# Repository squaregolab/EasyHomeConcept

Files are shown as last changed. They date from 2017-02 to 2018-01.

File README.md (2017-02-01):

# Easy Home Concept

## AVERTISEMENT
Ce projet étant encore en développement, il ne peut en aucun cas être utilisé en l'état dans une maison !

Nous n'avons pas encore abordé les différents problèmes liés à la securité ou encore l'interfaçage avec (par exemple)
des volets de constructeurs différents.

## Principe du projet

Le but de ce projet est de proposer un système simple et à bas coût afin de pouvoir domotiser sa maison.

Le but final du projet étant de pouvoir contrôler les principaux acteurs de la maison (lumière, volets, chauffage) ainsi que de pouvoir ajouter facilement au système divers acteurs.

## Solution utilisée

### Materiél

Pour le centre de contrôle, nous avons choisi une Raspberry Pi 3 ainsi qu'un écran tactile de 7".
Le choix s'est posé sur la Raspberry pi 3 car elle dispose du Wifi à l'origine ainsi que la facilité de connexion d'un écran.

Pour ce qui est des modules de contrôle, nous avons fait le choix d'en disposer un dans chaque pièce (aspect modulaire). Ces modules sont équipés d'un Adafruit Huzzah ainsi qu'un GPIO Expander (MCP23008).

### Logiciel

Le programme de la Rapsberry est en fait le serveur, les modules sont donc les clients.

Le serveur ainsi que l'interface de la raspberry sont développé en Java (JavaFx pour l'interface) avec l'IDE Intellig IDEA.
Les différentes bibliothèques utilisées sont présente dans Libraries, les sources sont également disponibles.

Pour les Huzzahs, le programe est développé en C++/Arduino via PlatforIO (extention de Atom).
Les sources sont également disponibles dans Sources.

### Communication

La Communication Serveur/Clients se fait pour le moment via une connection TCP/IP.

#### Presentation des trames

###### Trame de demande:
>`<q>`
><p>Le serveur envoi une demande d'actualisation au client.</p>

###### Trame de commande:
>`<c,"ID","valeur">`
><p>Le serveur envoi une commande identifiée par un ID numérique suivi par la valeur à appliquer, le tout séparé par une virgule. </p>
> <p>A l'heure actuelle, les commandes disponibles sont les suivantes</p>
>
> 1. Lumière<br> ID => 1<br>Commandes:
>     * 0 = Eteindre
>     * 1 = Allumer
> 1. Volets<br> ID => 2<br>Commandes:
>     * 0 = Stop
>     * 1 = Fermer
>     * 2 = Ouvrir
> 1. Température Cible<br>ID => 3<br>Commande: _Température_
> 1. Chauffage<br>ID => 4<br>Commandes:
>     * 0 = Eteindre
>     * 1 = Allumer  

###### Trame de réponse:
>>La trame de réponse suivante est donnée pour les modules que nous avons conçu. Cette trame pourra être modifiée afin d'accepter des modules divers.

>`<r,"IDmodule","Temperature","TemperatureCible","Humidité","EtatLumiere","EtatVollet","ConsoEau","EtatChauffage">`
>

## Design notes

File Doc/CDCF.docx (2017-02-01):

Promotion 2016-2019 | Imerir

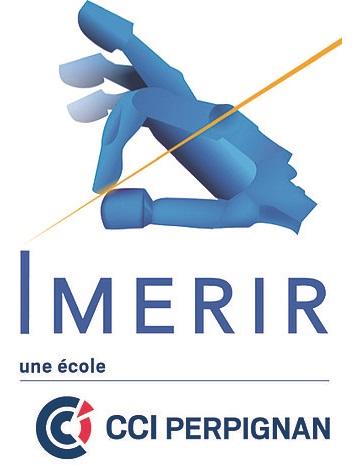
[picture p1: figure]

CDCF

Maison domotique

REY Clément

CLEMENT Sébastien

08 décembre 2016

Version 1.0

# Sommaire

Expression fonctionnel du besoin 2

Réaliser une installation domotique 2

# Expression fonctionnel du besoin

## Réaliser une installation domotique

L’application doit permettre :

- de connaître :
  - la température et l’humidité dans la maison.
  - des données tel que la consommation d’eau et d'électricité
- de contrôler :
- l’éclairage
- les volets
- la climatisation / chauffage

Le système doit être pilotable depuis un écran de contrôle tactil.

Les données doivent être consultable sur une application mobile qui peut aussi permettre de contrôler les éléments de la maison.

L'installation doit être facile.

Il doit y avoir une possibilité d’ajouter des éléments (capteur, actionneur)

CDCF_REY-CLEMENT_V1.0

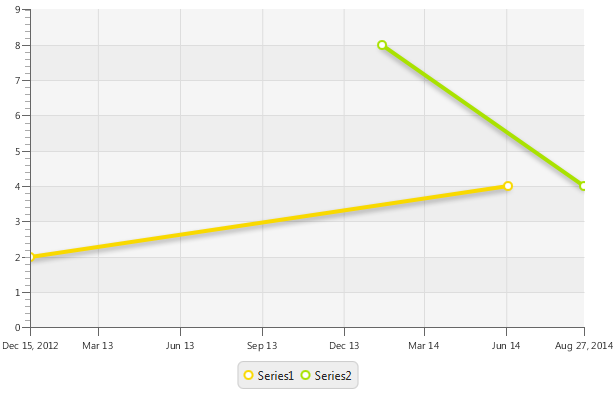
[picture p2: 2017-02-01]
Sources/InterfacePi/src/extfx/scene/chart/doc-files/DateAxisMonths.png

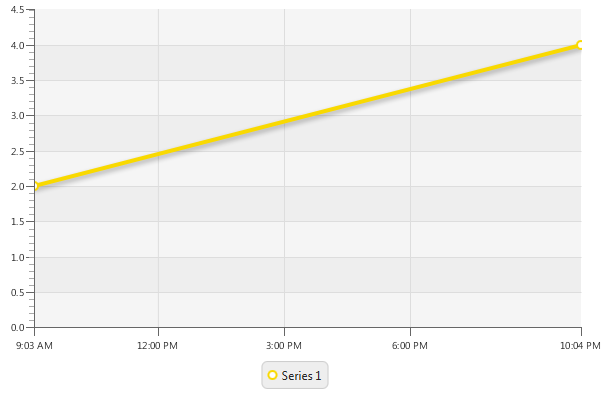
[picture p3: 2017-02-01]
Sources/InterfacePi/src/extfx/scene/chart/doc-files/DateAxisHours.png

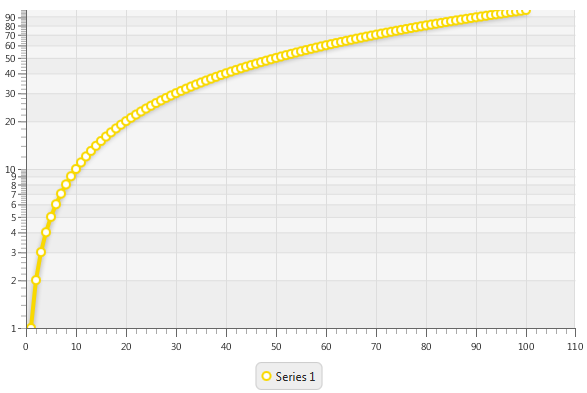
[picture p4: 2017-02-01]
Sources/InterfacePi/src/extfx/scene/chart/doc-files/LogarithmicAxis.png

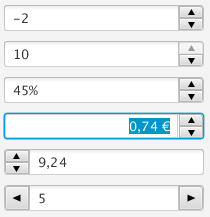
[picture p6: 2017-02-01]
Sources/InterfacePi/src/extfx/scene/control/doc-files/NumberSpinner.png

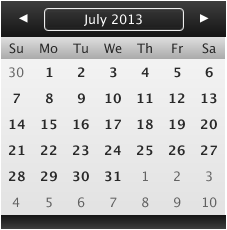
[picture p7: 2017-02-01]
Sources/InterfacePi/src/extfx/scene/control/doc-files/CalendarView.png

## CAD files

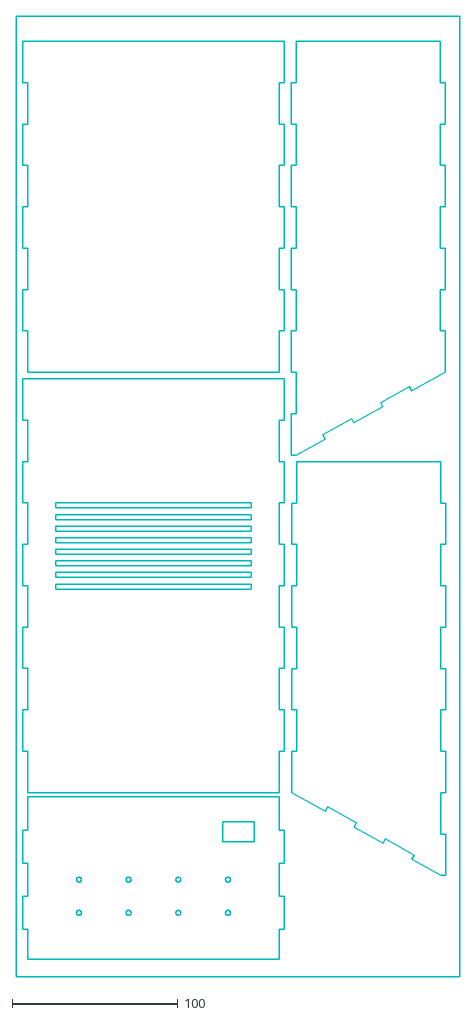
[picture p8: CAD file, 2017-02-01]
Sources/Modeles sketchups/Boitier Alim stabilisée/dessin.dxf
268.0 x 580.0

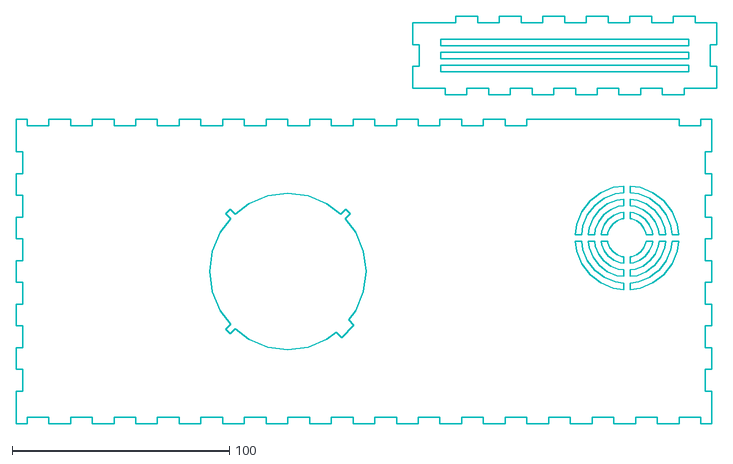
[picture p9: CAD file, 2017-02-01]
Sources/Modeles sketchups/Boitier RaspB - ecran tactil/boitier1.dxf
322.4 x 187.4

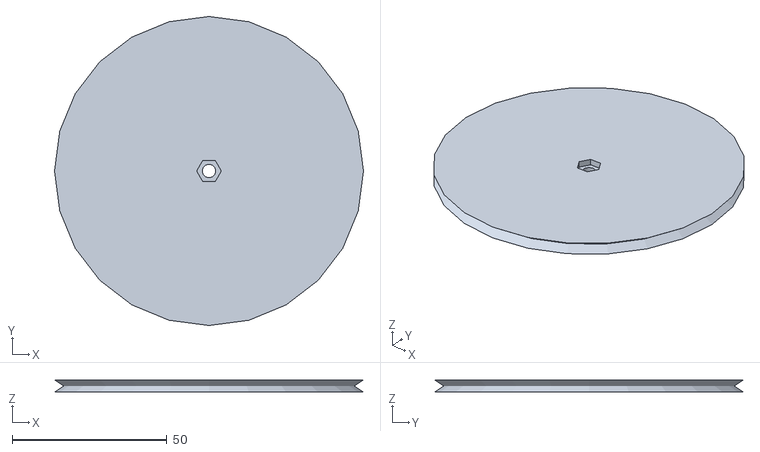
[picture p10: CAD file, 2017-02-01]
Sources/Modeles sketchups/coupleur moteur/démultiplicateur.stl
100.0 x 100.0 x 4.00

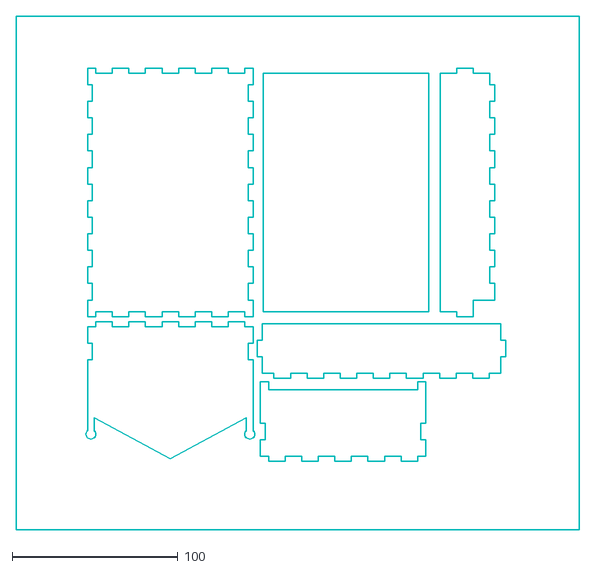
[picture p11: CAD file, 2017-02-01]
Sources/Modeles sketchups/Lit huzzah/dessin.dxf
340.0 x 310.0

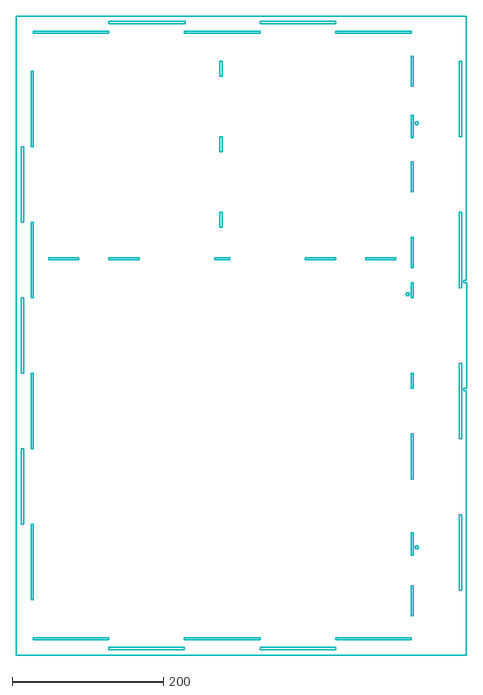
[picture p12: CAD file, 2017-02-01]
Sources/Modeles sketchups/Maquette maison/plaque1.dxf
597.0 x 846.0

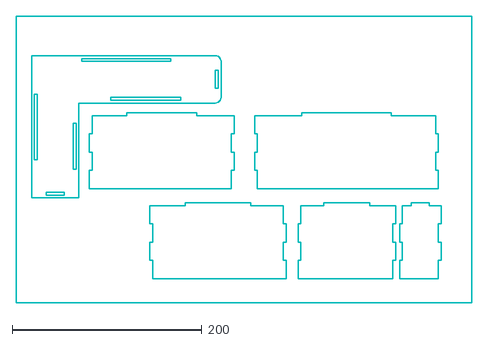
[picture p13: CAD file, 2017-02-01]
Sources/Modeles sketchups/Meuble/meubles1.dxf
481.0 x 302.0

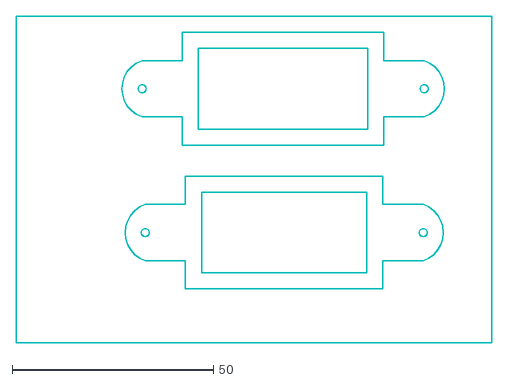
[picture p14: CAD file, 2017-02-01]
Sources/Modeles sketchups/support moteur/dessin.dxf
118.0 x 81.0

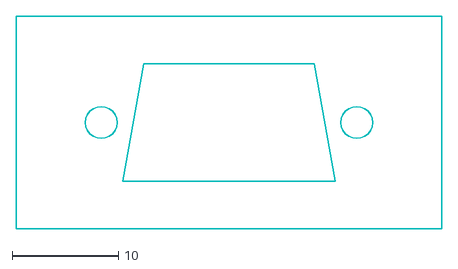
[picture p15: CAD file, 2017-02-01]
Sources/Modeles sketchups/Tableau elec/dessin.dxf
40.0 x 20.0

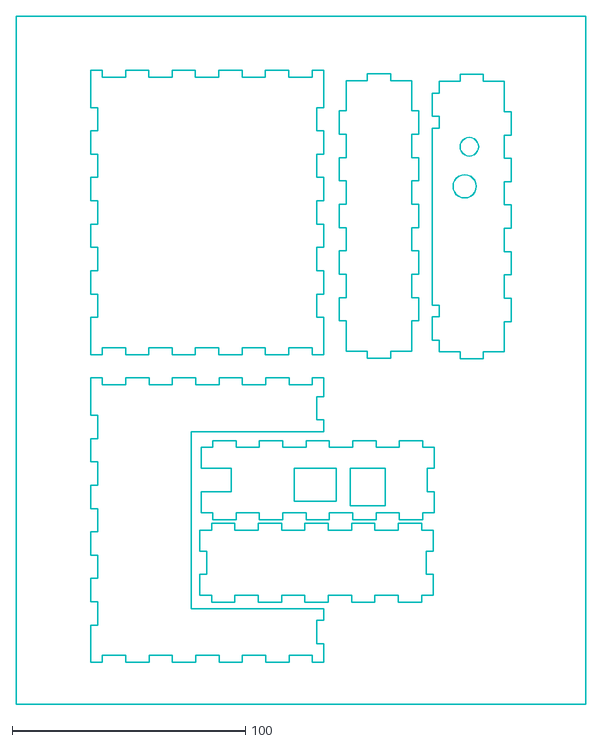
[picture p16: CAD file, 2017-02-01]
Sources/Modeles sketchups/Tele/dessin-1.dxf
244.0 x 295.0

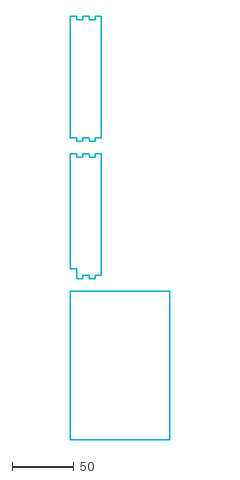
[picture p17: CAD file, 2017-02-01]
Sources/Modeles sketchups/ventilo/dessin.dxf
80.0 x 342.0

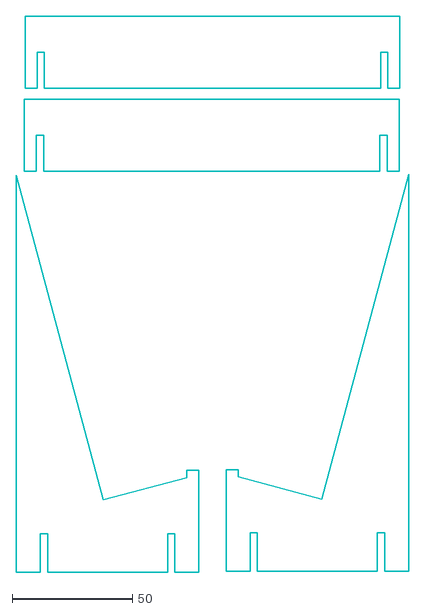
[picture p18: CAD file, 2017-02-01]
Sources/Modeles sketchups/Boitier RaspB - ecran tactil/porte boitier.dxf
163.3 x 231.5

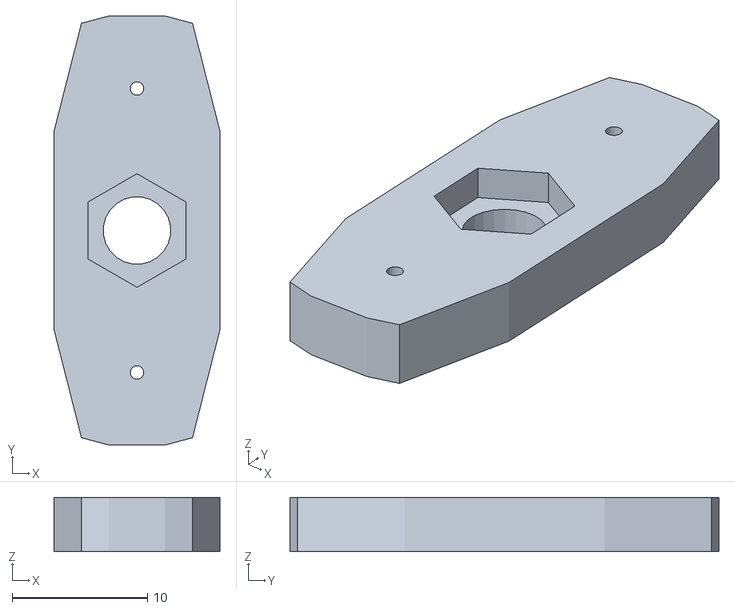
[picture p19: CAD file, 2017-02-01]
Sources/Modeles sketchups/coupleur moteur/coupleur moteur2.stl
12.2 x 31.7 x 4.00

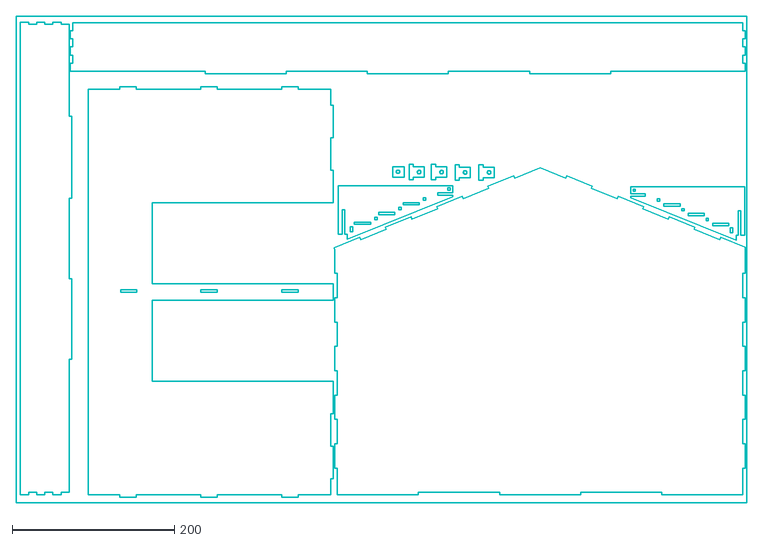
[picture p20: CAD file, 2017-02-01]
Sources/Modeles sketchups/Maquette maison/plaque4.dxf
900.0 x 600.0

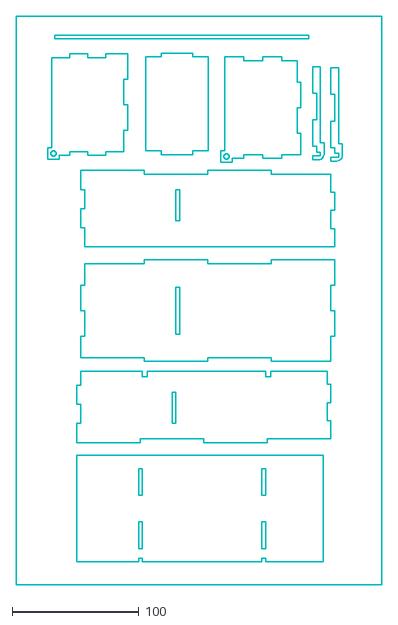
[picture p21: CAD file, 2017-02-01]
Sources/Modeles sketchups/Meuble/dessin4.dxf
288.0 x 448.0

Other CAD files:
Sources/Modeles sketchups/ventilo/dessin-1.dxf
Sources/Modeles sketchups/coupleur moteur/coupleur moteur0.stl
Sources/Modeles sketchups/Maquette maison/plaque5.dxf
Sources/Modeles sketchups/Meuble/tapis.dxf
Sources/Modeles sketchups/Boitier Alim stabilisée/Alim stabilisée.skp
Sources/Modeles sketchups/Boitier RaspB - ecran tactil/Boitier RaspB - ecran tactil.skp
Sources/Modeles sketchups/Lit huzzah/Lit huzzah.skp
Sources/Modeles sketchups/Maquette maison/Maquette maison.skp
Sources/Modeles sketchups/Maquette maison/plaque2.dxf
Sources/Modeles sketchups/Maquette maison/plaque3.dxf
Sources/Modeles sketchups/Meuble/dessin2.dxf
Sources/Modeles sketchups/Meuble/dessin3.dxf
Sources/Modeles sketchups/Meuble/meuble2.skp
Sources/Modeles sketchups/Meuble/meubles.skp
Sources/Modeles sketchups/Meuble/meubles4.skp
Sources/Modeles sketchups/Meuble/tapis2.dxf
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

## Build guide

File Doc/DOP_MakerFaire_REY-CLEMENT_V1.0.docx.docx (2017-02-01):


Promotion 2016-2019

Imérir

Dossier d’Organisation Projet

Domotique sur Raspberry PI

Clément Rey

Sébastien Clément

06/12/16

Version 1.0

Ref DOP_Domotique_REY-CLEMENT_V1.0

# Historique des versions

Version | date | Modifications | Pages modifiées (1)
0.1 | 06/12/16 | Création du document | toutes

(1) si modification globale, indiquer « toutes »

# Sommaire

1. Cadre et objectifs du projet

2. Tâches et planning

3. Organisation

4. Tableau des risques

5. Qualité

6. Capitalisation de l’expérience

# 1. Cadre et objectifs du projet

Dans le cadre du salon « Mini Maker Faire » organisé par l’IMERIR fin janvier, nous avons choisi de réaliser un projet de domotique. L’objectif de ce projet est de réaliser une maquette d’application fonctionnelle à présenter le jour du salon.

# 2. Tâches

- Mise en place du projet
  - Rédiger les documents de gestion et planning
  - Créer dépôt pour le travail collaboratif
  - Définir la charte graphique
  - Définir le matériel nécessaire
  - Faire passer la commande de matériel
- Programmation
  - Programmation de la Raspberry
    - Configuration / installation de la raspberry
    - Gérer la centralisation des données
    - Gérer la commande des élément distants
    - Créer l'interface graphique pour l'écran
    - Gérer l'envoi de données vers la database
  - Programmation des éléments distants
    - Gérer l'envoie des données vers raspberry
    - Gérer la réception des commandes de la raspberry
- Modélisation
  - Dessin des plans de la maquette
  - Impression de la maquette
  - Montage des modules

Montage maquette

# 3. Organisation

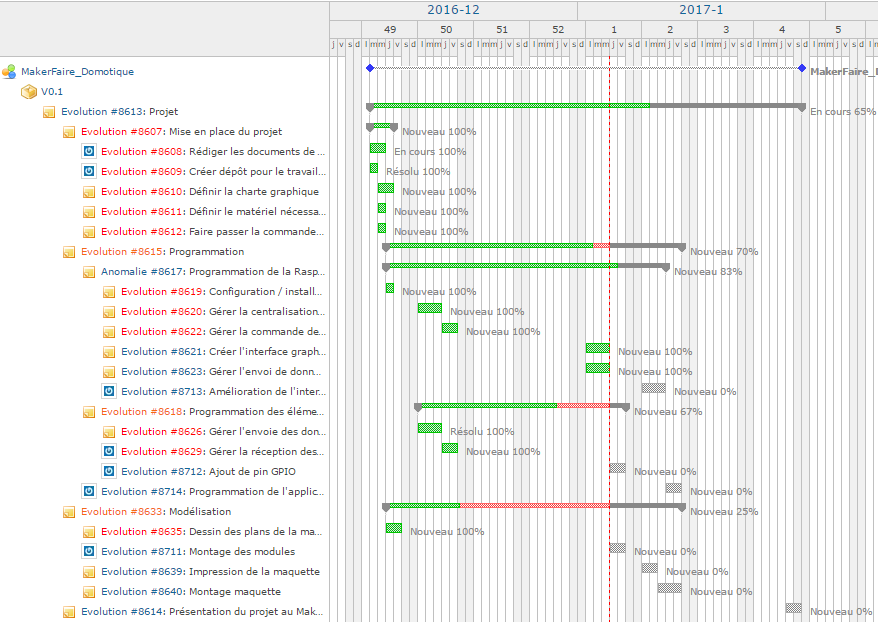
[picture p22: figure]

# 4. Tableau des risques

Management | Proba | Gravité | Criticité | Actions | responsable | etat
Retard projet | 2 | 5 | 10 | Bien planifier les différentes tâches du projet | chef de projet | ok
Manque d'information | 3 | 4 | 12 | Organiser des réunions de points au moins une fois par semaine | chef de projet | ok
Equipe Malade | 1 | 3 | 3 | Dispersion des tâches en urgence si cela arrive | chef de projet | ok
Manque d’information sur le projet | 2 | 5 | 10 | Organiser des réunions de points au moins une fois par semaine | chef de projet | ok
Test non suffisant | 2 | 3 | 6 | Mettre en place une grille de tests | développeur | ok
Mauvaise estimation complexité | 3 | 3 | 9 | Pas d’action | 0 | 0
Travail trop lent | 1 | 4 | 4 | Faire un suivie d'avancement du projet | chef de projet | ok

Généraux
Accident | 1 | 3 | 3 | Pas d’action | 0 | 0

Technique
PB Réseaux | 1 | 4 | 4 | faire des essaie / prévoir solution de secour | développeur | ok
PB électrique | 1 | 4 | 4 | prévoir suffisamment de matériel | développeur | ok
BUG inexpliqué | 2 | 3 | 6 | documenter et commenter | développeur | ok
Sauvegarde insuffisante | 2 | 5 | 10 | Sauvegarde automatique | développeur | ok
Disque dur corrompu | 1 | 5 | 5 | Faire des sauvegardes sur d'autre support | chef de projet | ok
Bloquage technique | 4 | 4 | 16 | Anticiper les axes qui poseront problème / Contourné le problème | développeur | ok
Sauvegarde corrompu | 1 | 5 | 5 | Faire des sauvegardes sur d'autre support | chef de projet | ok
Programme mal organisé et illisible | 3 | 4 | 12 | Règles de codage ==> développeur qui vérifie régulièrement | développeur | ok

# 5. Qualité

La qualité du projet final pourra être classé en 4 points:

- Qualité faible:

Relevé de mesure en interne via un écran.

- Qualité moyenne

Relevé de mesure et commande d'appareil en interne via écran tactile.

- Qualité haute:

Relevé de mesure et commande d’appareil depuis une application

- Qualité optimal

Relevé de mesure et commande d’appareil depuis une application mobile, possibilité d’ajouter facilement de nouveau modules

# 6. Capitalisation de l’expérience

Cette expérience a permis de mettre en place les outils de gestion vus en cours. Nous avons travaillé presque totalement en indépendance et nous avons ainsi développé de multiples compétences techniques.

La segmentation et la répartition des tâches au départ étaient plutôt juste malgré un léger glissement dû à la quantité de travail qui n'a toutefois pas entraîné de retard.

Si un tel projet était à refaire il serait préférable de faire une meilleur estimation de la quantité de travail afin de faire appel à plus de mains d’oeuvre.

DOP_Domotique_REY-CLEMENT_V1.0

Dossier d’Organisation Projet

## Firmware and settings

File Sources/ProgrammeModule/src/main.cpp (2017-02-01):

#include <ESP8266WiFi.h>
#include <Arduino.h>
#include <ESP8266WiFiMulti.h>
#include <String.h>
#include <string>
#include <WiFiClient.h>
#include <DHT.h>
#include <Wire.h>
#include <Adafruit_MCP23008.h>
#include <Servo.h>


// Data wire is plugged into port 13 on the Arduino
// Connect a 4.7K resistor between VCC and the data pin (strong pullup)
#define DHTPIN 13
#define DHTTYPE DHT22
DHT dht(DHTPIN,DHTTYPE);

Servo myservo;  // create servo object to control a servo
Adafruit_MCP23008 mcp; // create an extender object for more GPIO
ESP8266WiFiMulti WiFiMulti; // Use WiFiClient class to create TCP connections
WiFiClient client; // Client define as wifi target

// WiFi credentials.
const char* WIFI_SSID = ""; // The wifi name
const char* WIFI_PASS = ""; // The password
// If it's an open network, no need of PW;   !! Remove WIFI_PASS of WiFiMulti.addAP() func !!

const char* CLIENT_IP = "XX.XX.XX.XX";
const uint16_t CLIENT_PORT = 75; // Don't forget to open a port on your client


/******************************************************************
************************ Globals variables ************************
******************************************************************/

int id = 1; // Use one ID per rooms, don't forget to change between each.

float temp = 20;
float humi = 40;
bool etat_lum = 0;
bool etat_chauffage = 0;
int etat_volet = 1;
int waterConso = 0;

int cmd_lum = 0;
int cmd_volet = 0;
float cmd_temp = 18;

String splitedS[10];  // la trame recu de la raspberry découpé dans un tableau (<"type de trame C","numero de l'objet","etat de l'objet")

/*****************************************************************/
/****************** Déclaration des setup ************************/
/*****************************************************************/

void networkSetup()
{
    Serial.begin(115200);
    while(!Serial) { }

    // We start by connecting to a WiFi network
    WiFiMulti.addAP(WIFI_SSID, WIFI_PASS);
    // If it's an open network, no need of PW
    // !! Remove WIFI_PASS of WiFiMulti.addAP() func !!

    Serial.println();
    Serial.println();
    Serial.print("Wait for WiFi... ");

    while(WiFiMulti.run() != WL_CONNECTED)
    {
        Serial.print(".");
        delay(500);
    }

    Serial.println("");
    Serial.println("WiFi connected");
    Serial.println("IP address: ");
    Serial.println(WiFi.localIP());

    delay(500);

    Serial.print("connecting to ");
    Serial.println(CLIENT_IP);

    if (!client.connect(CLIENT_IP, CLIENT_PORT))
    {
        Serial.println("connection failed");
        Serial.println("wait 5 sec...");
        delay(5000);
    }
    else
    {
        client.println("<a," +String(id)+ ">"); // Send to the client your ID to open or not the connetion
        // if ID already use or not set in interface's parameters, the connexion is closed by the raspberry
    }
}

void pinSetup()
{
    pinMode (0,OUTPUT);
    digitalWrite (0,HIGH);
    myservo.attach(14);
    dht.begin();
}

void extenderSetup()
{
    mcp.begin();      // use default address 0

    mcp.pinMode(0, OUTPUT); //Moteur volet              // Shutter's Servo data
    mcp.pinMode(1, OUTPUT); //Libre                     // free pin
    mcp.pinMode(2, OUTPUT); //Ventilation               // Switch 1:on/0:off for the blower
    mcp.pinMode(3, OUTPUT); //Chaud                     // set the blower as heater
    mcp.pinMode(4, OUTPUT); //Froid                     // set the blower as cooler
    mcp.pinMode(5, INPUT);  //Consomation d'eau         // Water outflow counter
    mcp.pinMode(6, INPUT);  //Libre                     // free pin
    mcp.pinMode(7, OUTPUT); //Lumière                   // Light control

}

/*****************************************************************/
/*****************************************************************/
/*****************************************************************/

void getData()
{
    // Reading temperature or humidity takes about 250 milliseconds!
    // Sensor readings may also be up to 2 seconds 'old' (its a very slow sensor)
    float h = dht.readHumidity();
    humi = h;

    // Read temperature as Celsius (the default)
    float t = dht.readTemperature();
    temp = t;

    // Check if any reads failed and exit early (to try again).
    if (isnan(h) || isnan(t))
    {
        Serial.println("Failed to read from DHT sensor!");
        return;
    }

    // Serial.print("Humidity: ");
    // Serial.print(h);
    // Serial.print(" %\t");
    // Serial.print("Temperature: ");
    // Serial.print(t);
    // Serial.println(" *C ");
}

/*****************************************************************/
/*****************************************************************/

// Use to split the request string into usable datas
int splitString(String request, char separator)
{
    String curentString="                   ";
    memset(splitedS,0,sizeof(splitedS));
    int numChamp = 0, numLettre = 0;

    for (int i = 1 ; i < request.length() ; i++)
    {
        // each time there is a separator the currentString is push in the splitedS tab
        if (request[i] == separator || request[i] == '>')
        {
            curentString.remove(numLettre);
            splitedS[numChamp] = curentString;
            curentString="                   ";

            numLettre=0;
            numChamp++;
        }
        // all consecutive char is puch at the end of the currentString
        else
        {
            curentString.setCharAt(numLettre,request.charAt(i));
            numLettre++;
        }
    }
    return numChamp; // return the number of string in the splitedS tab
}

/*****************************************************************/
/*****************************************************************/

void lightControl()
{
    if (cmd_lum)
    {
        //Serial.println("Lumière alumée");
        mcp.digitalWrite (7,HIGH);
    }
    else
    {
        //Serial.println("Lumière éteinte");
        mcp.digitalWrite (7,LOW);
    }
}

/*****************************************************************/
/*****************************************************************/

void temperatureControl()
{
    //the blower system will turn off when the temperature is close to the target. Here 0.5 °c

    //Serial.print("Ventillation en mode : ");
    if (cmd_temp > (temp+0.5) && etat_chauffage)
    {
        //Serial.println("Chauffage");
        mcp.digitalWrite (2,HIGH);
        mcp.digitalWrite (3,HIGH);
        mcp.digitalWrite (4,LOW);
    }
    else if (cmd_temp < (temp-0.5) && etat_chauffage)
    {
        //Serial.println("Climatisation");
        mcp.digitalWrite (2,HIGH);
        mcp.digitalWrite (3,LOW);
        mcp.digitalWrite (4,HIGH);
    }
    else
    {
        //Serial.println("Arret");
        mcp.digitalWrite (2,LOW);
        mcp.digitalWrite (3,LOW);
        mcp.digitalWrite (4,LOW);
    }

}

/*****************************************************************/
/*****************************************************************/

// This fonction need to be revised to add other datas in the transmisons if necessary
void sendData()
{
    static long timer = 0;
    // to avoid more than 1 getData() each 2 seconds; due to the slowness of DHT22
    if (timer <= millis())
    {
        getData();
        timer = millis() + 2000;
    }
    // datas need to be turned into string before sending
    String toSend = "<r," + String(id) + "," +String(temp)+ "," +String(cmd_temp)+ "," +String(humi)+ "," +String(etat_lum)+ "," +String(etat_volet)+ "," +String(waterConso)+","+ String(etat_chauffage)+">";
    client.println(toSend); // This will send the request to the raspberry
    waterConso = 0;
}

/*****************************************************************/
/*****************************************************************/

void shutterControl()
{
    #define tempsFonc 20
    //this are the differents commands
    #define stop 0
    #define fermer 1
    #define ouvrir 2
    //this are the differents states
    #define entreOuvert 0
    #define ferme 1
    #define ouvert 2
    #define montee 3
    #define descente 4

    #define min 0
    #define max 180
    #define speed 1

    static long shutterTimer = millis();
    long actualTime = millis();
    static int pos = min;

    switch (cmd_volet)
    {
        case stop:
          if (min < pos && pos < max)
            etat_volet = entreOuvert;
          if (pos > max)
            etat_volet = ouvert;
          if (pos < min)
            etat_volet = ferme;
          break;
        case ouvrir :
          if (pos < max)
          {
              if (shutterTimer < actualTime)
              {
                  pos += speed;
                  shutterTimer = actualTime + tempsFonc;
              }
              etat_volet = montee;
          }
          else
          {
              etat_volet = ouvert;
          }
          break;
        case fermer :
          if (min < pos)
          {
              if (shutterTimer < actualTime)
              {
                  pos -= speed;
                  shutterTimer = actualTime + tempsFonc;
              }
              etat_volet = descente;
          }
          else
          {
              etat_volet = ferme;
          }
          break;
        default :
          Serial.println("Erreur case volet");
    }
    if (id == 1)
        myservo.write(pos);
    if (id == 2)
      myservo.write(180-pos); // ferme le volet dans l'autre sens
      // close the shutter in the other way around
}

/*****************************************************************/
/*****************************************************************/

void whatToDo(String cmdIDS, String cmdDataS)
{
    // this are the possibles values of the second field of the frame
    // they are IDs of the devices to control
    #define light 1
    #define volet 2
    #define temperature 3
    #define OnOff_temp 4

    // when the system recive a frame like : <c,IDofCommand,ValueOfCommand> this function occures
    // the IDofCommand is use for the switch, then the new value is push into the variables and call the assotiate contol function
    int cmdID = cmdIDS.toInt();
    switch (cmdID)
    {
        case light : //identifiant pour la lumiere
          cmd_lum = cmdDataS.toInt();
          etat_lum = cmd_lum;
          lightControl();
          break;
        case volet : //identifiant pour les volet
          cmd_volet = cmdDataS.toInt();
          shutterControl();
          break;
        case temperature : //identifiant pour le controle de la température
          cmd_temp = cmdDataS.toFloat();
          temperatureControl();
          break;
        case OnOff_temp :
          etat_chauffage = cmdDataS.toInt();
          break;
    }
    sendData();
}

/*****************************************************************/
/*****************************************************************/

void frameTraitment()
{
    // This function read the buffer char by char from '<' until '>'
    #define closed 0
    #define open 1
    static String request;
    static bool first = true;
    String finalRequest;

    static bool trame = closed;
    char newChar;


    if(first)
    {
        request.reserve(24);
        first = false;
    }
    newChar = client.read();

    if (newChar == '<')
    {
        trame = open;
        request = '<';
    }
    else if (trame == open)
    {
        if ('!' < newChar && newChar < '~')
        {
            request=request+newChar;
            if (newChar == '>')
            {
                trame = closed;
                finalRequest = request;
                request = "";
            }
        }
        else
        {
           request = "";
        }
        if (trame == closed)
        {
            int nbSeparator = splitString(finalRequest, ',');
            for (int i = 0; i < nbSeparator; i++)
            {
                if (splitedS[i] == "c")
                {
                    whatToDo(splitedS[i+1],splitedS[i+2]);
                    finalRequest = "";
                    break;
                }
                else if (splitedS[i] == "q")
                {
                    sendData();
                    finalRequest = "";
                }
            }
        }
    }
}

/*****************************************************************/
/*****************************************************************/

bool wifiTest()
{
    if(WiFi.status() != WL_CONNECTED) // test de connection au reseau wifi
    {
        Serial.println("Disconnected from WiFi");
    }
    return WiFi.status();
}

/*****************************************************************/
/*****************************************************************/

bool testClient()
{
    if (!client.connected())
    {
        Serial.println("Disconnected from Client");
        while (!client.connect(CLIENT_IP, CLIENT_PORT))
        {
            Serial.println("wait 5 sec...");
            delay(5000);
            Serial.println("Reconnection failed");
        }
        client.println("<a," +String(id)+ ">");
        Serial.println("Reconnected to Client");
    }
    return client.connected();
}

/*****************************************************************/
/*****************************************************************/

void waterCounter()
{
    // for a sensor that return pulse for one liter
    if (mcp.digitalRead(5) == true )
    {
        waterConso = 1;
    }
}

/******************************************************************
**************************** Setup ********************************
******************************************************************/

void setup()
{
    networkSetup();
    pinSetup();
    extenderSetup();
}

/******************************************************************
**************************** Loop *********************************
******************************************************************/

void loop()
{
    if(testClient() && wifiTest()) // test de connection au client
    {
        frameTraitment();
        lightControl();
        shutterControl();
        temperatureControl();
        waterCounter();
    }

}

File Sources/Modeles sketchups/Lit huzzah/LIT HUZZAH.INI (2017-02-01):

[Technics_Laser_Data]
ModifyTechCFG=2
LayersNumber=1
ExportRows=1
ExportColumns=1
ExportRowSpace=0.00000
ExportColumnSpace=0.00000
ExportRowCW=0.00000
ExportColumnCW=0.00000
LogicOrgPositionX=734.10232
LogicOrgPositionY=423.84083
LogicOrgPositionZ=-9999999.00000
AtOnceExport=1
IsTwoLaserWorking=1
TableZeroPositionX=0.00000
TableZeroPositionY=0.00000
OutputTimes=1
DelayTime=0
FeedLength=0.00000
FeedSpeed=5.00000
FeedDelayTime=0
MinX=322.03483
MaxX=734.10232
MinY=189.25960
MaxY=423.84083
ChangeSerialNo=0
ArrayMinX=322.03483
ArrayMaxX=734.10232
ArrayMinY=189.25960
ArrayMaxY=423.84083
ClipBoxPower=40.00000
ClipBoxPower2=40.00000
ClipBoxOffsetLen=2.00000
ClipBoxSpeed=25.00000
AlignMachineZPos=0.00000
RouteLength=0.00000
RoutePointNumber=0
OffsetLaserPower=0.00000
OffsetWorkSpeedPer=1.00000
ZHeightForLaserFocus=0.00000
LayerColor_0=32768
[CoordSystem_0]
LogicOrgPosition1=734.10232
LogicOrgPosition2=423.84083
LogicOrgPosition3=-9999999.00000
SPLITBLOCK_NUMBER=0
[CreateTechnicsCodeMgr]
PrjHasModifyCFG=1
[TechnicsLayers_16776960]
TechnicsMode=TECHNICS_LASERCUT
LaserCutConnerPower=20.00000
LaserCutWorkPower=100.00000
LaserCutConnerPower2=30.00000
LaserCutWorkPower2=50.00000
LaserCutFrequency=20000
LaserCutOptimizePathType=1
LaserCutInnerToOuter=1
LaserCutInnerToOuter2=0
LaserCutDownToUpper=1
LaserCutBlockHeight=150.00000
LaserCutAutoSetPathDir=1
LaserCutCicleMinSegNumber=36
LaserCutDisperseLength=0.02000
LaserCutCloseGapLength=0.11000
LaserCutOverlapLength=0.00000
LaserCutAdjustForClose=0
LaserCutQXEnterLength=0.00000
LaserCutDelayMoveTime=0.00000
LaserCutOpenGZDelayTime=0.00000
LaserCutOpenLaserDelayTime=0.00000
LaserCutCloseLaserDelayTime=0.00000
LaserCutDelayTimeAfterCloseLaser=0.00000
LaserCutOneAxisBackLashLength=0.00000
LaserCutTwoAxisBackLashLength=0.00000
LaserCutBackLashAddSpaceLength=8.00000
LaserCutBlowGasType=2
LaserCutAheadBlowGasTimes=0.00000
LaserCutNoCloseGasTimes=0.00000
LaserCutSpeed=15.00000
LaserCutGWAcc=120.00000
LaserCutGWTime=0.01000
LaserCutTrackSize=100
LaserCutLineLength=0.00000
SpaceCutLineLength=0.00000
bSpaceLineFirst=0
LaserCutAdjustMove=0
LaserCutAdjustMoveDelay=0.00000
LaserCutUpLen=0.00000
LaserCutCircleSpeedNum=0
[TechnicsLayers_8421376]
TechnicsMode=TECHNICS_LASERCUT
LaserCutConnerPower=20.00000
LaserCutWorkPower=100.00000
LaserCutConnerPower2=30.00000
LaserCutWorkPower2=50.00000
LaserCutFrequency=20000
LaserCutOptimizePathType=1
LaserCutInnerToOuter=1
LaserCutInnerToOuter2=0
LaserCutDownToUpper=1
LaserCutBlockHeight=150.00000
LaserCutAutoSetPathDir=1
LaserCutCicleMinSegNumber=36
LaserCutDisperseLength=0.02000
LaserCutCloseGapLength=0.11000
LaserCutOverlapLength=0.00000
LaserCutAdjustForClose=0
LaserCutQXEnterLength=0.00000
LaserCutDelayMoveTime=0.00000
LaserCutOpenGZDelayTime=0.00000
LaserCutOpenLaserDelayTime=0.00000
LaserCutCloseLaserDelayTime=0.00000
LaserCutDelayTimeAfterCloseLaser=0.00000
LaserCutOneAxisBackLashLength=0.00000
LaserCutTwoAxisBackLashLength=0.00000
LaserCutBackLashAddSpaceLength=8.00000
LaserCutBlowGasType=2
LaserCutAheadBlowGasTimes=0.00000
LaserCutNoCloseGasTimes=0.00000
LaserCutSpeed=15.00000
LaserCutGWAcc=120.00000
LaserCutGWTime=0.01000
LaserCutTrackSize=100
LaserCutLineLength=0.00000
SpaceCutLineLength=0.00000
bSpaceLineFirst=0
LaserCutAdjustMove=0
LaserCutAdjustMoveDelay=0.00000
LaserCutUpLen=0.00000
LaserCutCircleSpeedNum=0
[TechnicsLayers_8388672]
TechnicsMode=TECHNICS_LASERCUT
LaserCutConnerPower=20.00000
LaserCutWorkPower=100.00000
LaserCutConnerPower2=30.00000
LaserCutWorkPower2=50.00000
LaserCutFrequency=20000
LaserCutOptimizePathType=1
LaserCutInnerToOuter=1
LaserCutInnerToOuter2=0
LaserCutDownToUpper=1
LaserCutBlockHeight=150.00000
LaserCutAutoSetPathDir=1
LaserCutCicleMinSegNumber=36
LaserCutDisperseLength=0.02000
LaserCutCloseGapLength=0.11000
LaserCutOverlapLength=0.00000
LaserCutAdjustForClose=0
LaserCutQXEnterLength=0.00000
LaserCutDelayMoveTime=0.00000
LaserCutOpenGZDelayTime=0.00000
LaserCutOpenLaserDelayTime=0.00000
LaserCutCloseLaserDelayTime=0.00000
LaserCutDelayTimeAfterCloseLaser=0.00000
LaserCutOneAxisBackLashLength=0.00000
LaserCutTwoAxisBackLashLength=0.00000
LaserCutBackLashAddSpaceLength=8.00000
LaserCutBlowGasType=2
LaserCutAheadBlowGasTimes=0.00000
LaserCutNoCloseGasTimes=0.00000
LaserCutSpeed=15.00000
LaserCutGWAcc=120.00000
LaserCutGWTime=0.01000
LaserCutTrackSize=100
LaserCutLineLength=0.00000
SpaceCutLineLength=0.00000
bSpaceLineFirst=0
LaserCutAdjustMove=0
LaserCutAdjustMoveDelay=0.00000
LaserCutUpLen=0.00000
LaserCutCircleSpeedNum=0
TechnicsNeedOutput=0
[TechnicsLayers_1048455]
TechnicsMode=TECHNICS_LASERCUT
LaserCutConnerPower=20.00000
LaserCutWorkPower=100.00000
LaserCutConnerPower2=30.00000
LaserCutWorkPower2=50.00000
LaserCutFrequency=20000
LaserCutOptimizePathType=1
LaserCutInnerToOuter=1
LaserCutInnerToOuter2=0
LaserCutDownToUpper=1
LaserCutBlockHeight=150.00000
LaserCutAutoSetPathDir=1
LaserCutCicleMinSegNumber=36
LaserCutDisperseLength=0.02000
LaserCutCloseGapLength=0.11000
LaserCutOverlapLength=0.00000
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

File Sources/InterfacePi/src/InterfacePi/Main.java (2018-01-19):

package InterfacePi;


import InterfacePi.Communication.ClientS;
import InterfacePi.Communication.CommunicationScript;
import InterfacePi.Communication.ModuleLauncher;
import com.pi4j.io.gpio.*;
import com.pi4j.system.SystemInfo;
import javafx.application.Application;
import javafx.event.EventHandler;
import javafx.fxml.FXMLLoader;
import javafx.scene.Parent;
import javafx.scene.Scene;
import javafx.scene.input.MouseEvent;
import javafx.scene.paint.Color;
import javafx.stage.Stage;
import org.apache.logging.log4j.LogManager;
import org.apache.logging.log4j.Logger;

import java.io.*;
import java.net.Socket;
import java.util.HashMap;

public class Main extends Application {

    /******************
     *  StandBy Screen=
     ******************/
    public double timeForSleep=10;
    public int compteur;
    public boolean screenClicked=false;

    /***********************
     *  Client management
     ***********************/
    public static HashMap<Integer, ClientS> clientHashMap = new HashMap<>();   /*<!Table qui contient les diferent client configurer*/
    public static Socket socketScript;   /*<!Socket de connection au script Blynk*/
    public static CommunicationScript communicationScript =new CommunicationScript();   /*<!Class de getioon de la communication avec le script*/

    /***********************
     *  Screen management
     ***********************/
    public static int currentRoom =-1;
    public static int generalScreen;



    public static ModuleLauncher launcher = new ModuleLauncher();
    public static GpioPinDigitalOutput ventiloPin;

    /***********************
     *  Private Variable
     ***********************/
    private static Logger logger = LogManager.getLogger();
    private Stage primaryStageSave;



    @Override
    public void init() throws Exception {

    }

    @Override
    public void start(Stage primaryStage) throws Exception{



        Parent root = FXMLLoader.load(getClass().getResource("/InterfacePi/Interface/Home/home.fxml"));

        primaryStage.setTitle("Hello World");
        primaryStage.setScene(new Scene(root, 1024, 600));
        primaryStage.show();
        primaryStage.addEventFilter(MouseEvent.MOUSE_PRESSED, new EventHandler<MouseEvent>() {
            @Override
            public void handle(MouseEvent mouseEvent) {
                screenClicked=true;
            }
        });
        primaryStageSave=primaryStage;
        new StandByScreen().start();



        launcher.lauchAll();


    }


    public static void main(String[] args) {

        GpioController gpio = GpioFactory.getInstance();
        ventiloPin = gpio.provisionDigitalOutputPin(RaspiPin.GPIO_00, PinState.HIGH);
        ventiloPin.high();
        new GestionTemp().start();
        logger.info("**********************************************************************");
        logger.info("**********************************************************************");
        logger.info("**                           Welcome !                              **");
        logger.info("**                     This is a new start !                        **");
        logger.info("**********************************************************************");
        logger.info("**********************************************************************");
        logger.info("");
        logger.info("Yes, yes i now this is an awesome app made by un awesome guy! ;)");
        logger.info("");
        logger.info("Special thanks to SquareGoLab and IMERIR and Clement Rey for all their help!");
        logger.info("");
        logger.info("Powered by:");
        logger.info("");
        logger.info("");
        File file = new File("/home/pi/Interface/rasp");
        try {
            BufferedReader reader = new BufferedReader(new FileReader(file));
            String line;
            while((line = reader.readLine())!=null) {
                logger.info(line);
            }
            reader.close();
        } catch (FileNotFoundException e) {
            logger.catching(e);
        } catch (IOException e) {
            logger.catching(e);
        }
        logger.info("");
        logger.info("");
        logger.info("And:");
        logger.info("");
        logger.info("");
        file = new File("/home/pi/Interface/java");
        try {
            BufferedReader reader = new BufferedReader(new FileReader(file));
            String line;
            while((line = reader.readLine())!=null) {
                logger.info(line);
            }
            reader.close();
        } catch (FileNotFoundException e) {
            logger.catching(e);
        } catch (IOException e) {
            logger.catching(e);
        }

        logger.info("");
        logger.info("");


        launch(args);
    }


        public static class LauchScript extends Thread
    {
        Logger loggerScript = LogManager.getLogger(this);

        @Override
        public void run() {
            /*while(true)
            {*/
                logger.info("Starting Blynk Script...");
                try {
                    loggerScript.trace("Kill script if already start...");
                    ProcessBuilder killer = new ProcessBuilder("sudo", "killall","node");
                    Process processKiller = killer.start();
                    processKiller.destroy();
                } catch (IOException e) {
                    logger.catching(e);
                }
                try{
                    ProcessBuilder pb = new ProcessBuilder("node", "/home/pi/Interface/blynkScript.js");
                    Process p = pb.start();
                    InputStream is = p.getInputStream();
                    InputStreamReader isr = new InputStreamReader(is);
                    BufferedReader br = new BufferedReader(isr);
                    String line;
                    while ((line = br.readLine()) != null) {
                        loggerScript.trace(line);

                    }
                    p.destroy();


                } catch (IOException e) {
                    logger.catching(e);
                }
        }
    }

    /**
     * Class for manage the case Fan (Thread)
     */
    public static class GestionTemp extends Thread
    {
        float temp=0;
        @Override
        public void run() {
            while(true)
            {

                try {
                    Thread.sleep(2000);
                    temp=SystemInfo.getCpuTemperature();
                    if(ventiloPin.isHigh())
                    {
                        if(temp>=70)
                        {
                            ventiloPin.low();
                            logger.debug("Starting fan!");
                        }
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

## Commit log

2017-02-01 Correct wrong librarry & quick code clean
    Change Log4j Libraries & quick code cleaning
    [Main.java]
2017-02-01 Add files
    Adding all Sketchups Modeles and Modules programs
    [Alim stabilisée.skp, Boitier RaspB - ecran tactil.skp, Lit huzzah.skp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]
